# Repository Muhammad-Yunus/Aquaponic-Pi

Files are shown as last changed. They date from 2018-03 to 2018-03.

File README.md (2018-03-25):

# Aquaponic-Pi

### Diagram block and Pin Mapping

##### One Wire Pin (4x DS18B20 Digital Temperature Sensor):
- Data -> GPIO13 RPI Zero 

##### Water Level Sensor
- WL Sensor A -> GPIO22 RPI Zero
- WL Sensor B -> GPIO27 RPI Zero

##### Selenoid Valve
- SV A -> GPIO19 RPI Zero
- SV B -> GPIO26 RPI Zero

##### TDS Probe to analog interface to PCF8591
- Left analog TDS -> A0
- Right analog TDS -> A1



### Content in this repo :
- Board Schematics (Cad Soft Eagle)
- Board Layout (Cad Soft Eagle)
- Python program :
    a. DS18B20
    b. PCF8591
    c. Selenoid Valve
    d. Water Level
    e. TDS 

##### Design And Developed By :
- [Legendre Technology](https://www.facebook.com/LegendreTechnology/)
- (Ziath & Robby) PRC Dept.of Physics Bogor Agricultural University

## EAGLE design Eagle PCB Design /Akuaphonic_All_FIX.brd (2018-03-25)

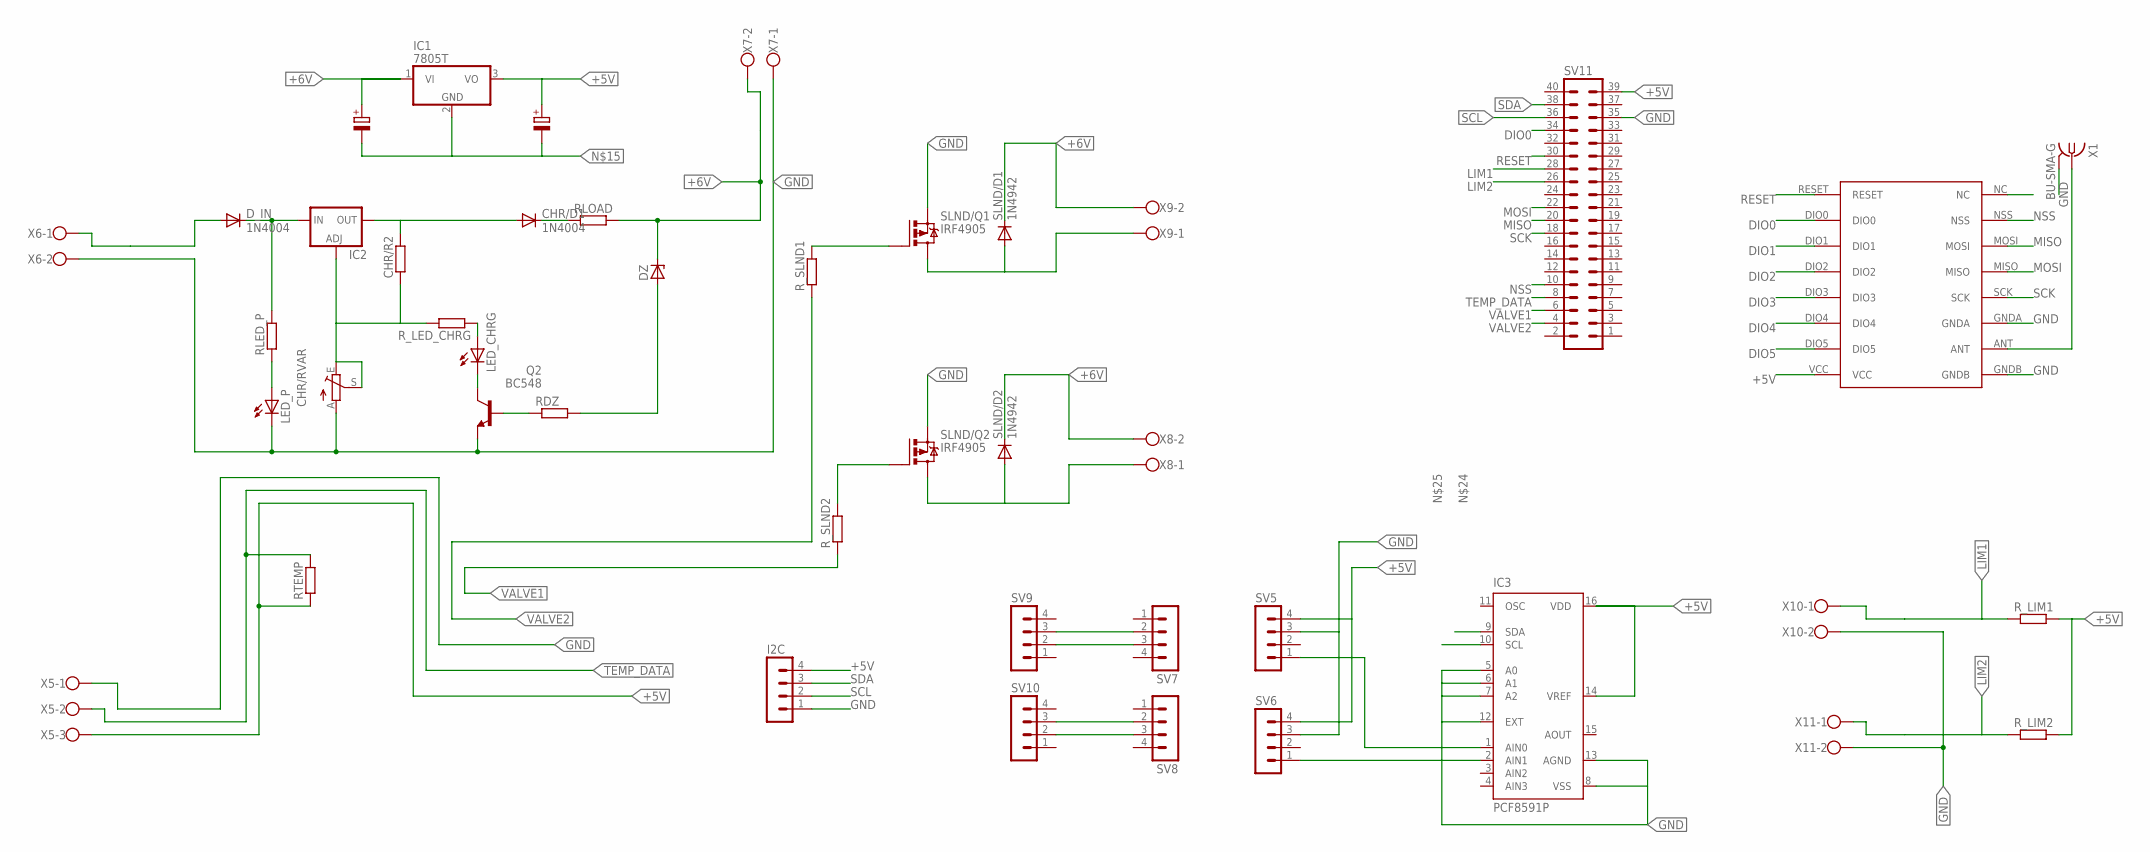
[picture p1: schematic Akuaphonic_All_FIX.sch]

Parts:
CHR/D1: 1N4004; DO41-10
CHR/R2: R0207/10; 0207/10
CHR/RVAR: TRIM_EU-B25P; B25P
DZ: ZENER-DIODEDO35Z10; DO35Z10
D_IN: 1N4004; DO41-10
I2C: MA04-1
IC1: 7805T; TO220H
IC2: LM317TL; 317TL
IC3: PCF8591P; DIL16
LED_CHRG: LED3MM
LED_P: LED3MM
Q2: BC548; TO92-EBC
RDZ: R0207/10; 0207/10
RLED_P: R0207/10; 0207/10
RLOAD: R0207/10; 0207/10
RTEMP: R0207/10; 0207/10
R_LED_CHRG: R0207/10; 0207/10
R_LIM1, R_LIM2: R0207/10; 0207/10
R_SLND1, R_SLND2: R0207/10; 0207/10
SLND/D1, SLND/D2: 1N4942; DO41-10
SLND/Q1, SLND/Q2: IRF4905; TO220BH
SV5, SV6, SV7, SV8, SV9, SV10: MA04-1
SV11: MA20-2
U$1: RFM69HW; RFM
X1: BU-SMA-G
X5: W237-103
X6, X7, X8, X9, X10, X11: W237-102

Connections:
+5V: I2C.4, IC1.3 (VO), IC3.14 (VREF), IC3.16 (VDD), RTEMP.1, R_LIM1.2, R_LIM2.2, SV5.4, SV6.4, SV11.39, U$1.VCC, X5.3
+6V: DZ.C, IC1.1 (VI), RLOAD.2, SLND/D1.C, SLND/D2.C, X7.2, X8.2, X9.2
DIO0: SV11.34, U$1.DIO0
DIO1: U$1.DIO1
DIO2: U$1.DIO2
DIO3: U$1.DIO3
DIO4: U$1.DIO4
DIO5: U$1.DIO5
DLOAD: CHR/D1.C, RLOAD.1
GND: CHR/RVAR.A, I2C.1, IC3.5 (A0), IC3.6 (A1), IC3.7 (A2), IC3.8 (VSS), IC3.12 (EXT), IC3.13 (AGND), LED_P.K (C), Q2.E, SLND/Q1.S, SLND/Q2.S, SV5.3, SV6.3, SV11.35, U$1.GNDA, U$1.GNDB, X1.2, X1.3 (2), X1.4 (2), X1.5 (2), X5.1, X6.2, X7.1, X10.2, X11.2
LIM1: R_LIM1.1, SV11.28, X10.1
LIM2: R_LIM2.1, SV11.26, X11.1
LM143: CHR/R2.1, CHR/RVAR.E, CHR/RVAR.S, IC2.1 (ADJ), R_LED_CHRG.2
MISO: SV11.20, U$1.MOSI
MOSI: SV11.22, U$1.MISO
unnamed: D_IN.A, X6.1
unnamed: LED_CHRG.K (C), Q2.C
unnamed: U$1.ANT, X1.1
unnamed: D_IN.C, IC2.3 (IN), RLED_P.2
unnamed: CHR/D1.A, CHR/R2.2, IC2.2 (OUT)
unnamed: SLND/D1.A, SLND/Q1.D, X9.1
unnamed: LED_P.A, RLED_P.1
unnamed: Q2.B, RDZ.1
unnamed: R_SLND1.2, SLND/Q1.G
unnamed: LED_CHRG.A, R_LED_CHRG.1
unnamed: SLND/D2.A, SLND/Q2.D, X8.1
unnamed: SV7.2, SV9.3
unnamed: R_SLND2.2, SLND/Q2.G
unnamed: SV7.3, SV9.2
unnamed: DZ.A, RDZ.2
unnamed: SV8.2, SV10.3
unnamed: SV8.3, SV10.2
unnamed: IC3.1 (AIN0), SV5.1
unnamed: IC3.2 (AIN1), SV6.1
NSS: SV11.10, U$1.NSS
RESET: SV11.30, U$1.RESET
SCK: SV11.18, U$1.SCK
SCL: I2C.2, SV11.36
SDA: I2C.3, SV11.38
TEMP_DATA: RTEMP.2, SV11.8, X5.2
VALVE1: R_SLND2.1, SV11.6
VALVE2: R_SLND1.1, SV11.4

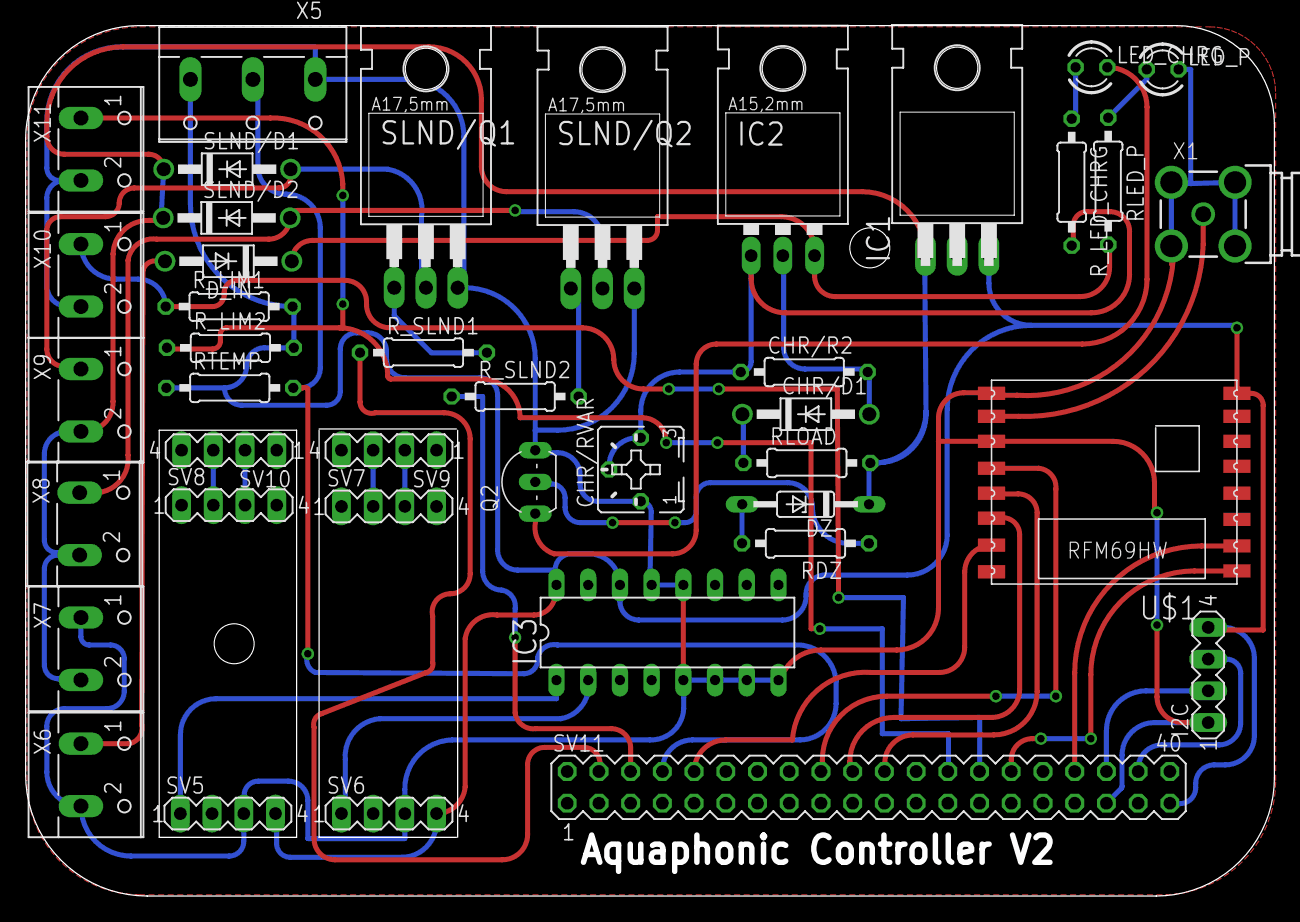
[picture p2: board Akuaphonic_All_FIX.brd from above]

Board: 2 copper layers, 100.0 x 69.7 mm, 41 parts (0 on the bottom side), 37 nets.

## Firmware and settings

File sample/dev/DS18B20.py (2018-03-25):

import os                                                  # import os module
import glob                                                # import glob module
import time                                                # import time module

os.system('modprobe w1-gpio')                              # load one wire communication device kernel modules
os.system('modprobe w1-therm')                                                 
base_dir = '/sys/bus/w1/devices/'                          # point to the address

device_folder = [0]*4
device_file = [0]*4
f = [0]*4
lines = [0]*4
equals_pos = [0]*4
temp_string = [0]*4
temp_c = [0]*4

for i in range(0,4):
	device_folder[i] = glob.glob(base_dir + '28*')[i]             # find device with address starting from 28*
	device_file[i] = device_folder[i] + '/w1_slave'                  # store the details
	print device_folder[i]

def read_temp_raw(i):
	   f[i] = open(device_file[i], 'r')
	   lines[i] = f[i].readlines()                                   # read the device details
	   f[i].close()
           return lines[i]

def read_temp(i):
	   lines[i] = read_temp_raw(i)
	   while lines[i][0].strip()[-3:] != 'YES':                   # ignore first line
	      time.sleep(0.2)
	      lines[i] = read_temp_raw(i)
	   equals_pos[i] = lines[i][1].find('t=')                        # find temperature in the details
	   if equals_pos[i] != -1:
	      temp_string[i] = lines[i][1][equals_pos[i]+2:]
	      temp_c[i] = float(temp_string[i]) / 1000.0                 # convert to Celcius
	      return temp_c[i]

while True:
	#for i in range(0,4):
	#   print "temp " + str(i) + " : " + str(read_temp(i))                                      # Print temperature    
	#   time.sleep(1)
	print "  T1 : " + str(read_temp(0)) , "  T2 : " + str(read_temp(1)) , "  T3 : " + str(read_temp(2)) , "  T4 : " + str(read_temp(3))
	time.sleep(1)

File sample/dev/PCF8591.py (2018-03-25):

#!/usr/bin/python
# -*- coding:utf-8 -*-
import smbus
import time

address = 0x48
A0 = 0x40
A1 = 0x41
A2 = 0x42
A3 = 0x43
A = [0x40, 0x41]
bus = smbus.SMBus(1)
value = [0]*2
while True:
	for i in range(0,2):
	    bus.write_byte(address,A[i])
	    value[i] = bus.read_byte(address)
	    time.sleep(0.1)
	    #print "AIN " + str(i) + " : " + str(value[i]*5.0/255)
	print "AIN 1 : " + "{:.2f}".format(value[0]*5.0/255), "   AIN 2 : " + "{:.2f}".format(value[1]*5.0/255)
	time.sleep(0.1)
